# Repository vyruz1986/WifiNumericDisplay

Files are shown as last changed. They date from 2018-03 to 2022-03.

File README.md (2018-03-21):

# WiFi numeric display

## Introduction

This project is a generic 4-digit 7-segment numeric display which can be controlled over WiFi.
It uses a Wemos D1 Mini MCU and TPIC6B595 power logic shift registers to control pieces of powerful, very bright 24V LED strip segments.
These displays are highly visible even in bright sunlight over a long distance (used in Fyball competitions where viewing distance is around 30 meters).

It was created for use in Flyball, but can easily be applied elsewhere

Pictures & video: https://goo.gl/photos/G3tg8hrfvAJZ6PEY8

## Hardware

-Under construction-

Basically this is a 'beefed up' version of [Sparkfun's large 7 segment displays](https://www.sparkfun.com/products/8530)
together with [Sparkfun's accompanying large digit driver boards](https://www.sparkfun.com/products/13279).

The code is 1:1 compatible, the difference with my project is that I use the following components
to allow for better visibility (moar light!):

|Part type			| Sparkfun part						| My Part																	| Description																|
| --- | --- | --- | --- |
| Digit segment		| [12 SMD LEDs per segment (200mcd)](https://www.sparkfun.com/datasheets/Components/YSD-1600AR6F-89.pdf) driven with 12V	| 10cm of [24V 240 LED/meter strip](http://s.click.aliexpress.com/e/3zjiyZV)	| These are larger, more powerful LEDs which are also denser positioned.	|
| Segment driver	| [TPIC6C596](https://cdn.sparkfun.com/datasheets/Widgets/TPIC6C596.pdf) | [TPIC6B595](https://www.reichelt.de/?ACTION=3;ARTICLE=147328;SEARCH=tpic) | Compatible chip which can handle the extra current that out LED strip segments will draw |

I will complete this section later with a description on how to make the display using 10cm LED strip pieces and an aluminium plate to mount them on.

## Flashing the firmware

The firmware should flash just fine using the Arduino IDE with ESP8266 support. Open the `SevenSegmentDisplay.ino` file, select Wemos D1 mini as the board and hit flash.

You might want to change the OTA flash password in the `SevenSegmentDisplay.ino` file, search for the following line:
`#define OTA_PASSWD "EnterUniquePasswordHere!"`

## Connection & protocol

### Connecting to the display

The display listens on TCP port 23, no authentication is currently supported. Up to 5 clients can be connected simultaneously.

### Supported messages

Currently 2 messages are supported:

* `CDnnnn`: Where `nnnn` is a number between 0 and 9999. This message will start a countdown of the given number in seconds.
* `nnnn`: Where `nnnn` is a number between 0 and 9999. The number is expected to be an amount of time in hundredths of seconds. The time will be displayed in the format of SS.ss. e.g. sending `1234`, the display will show 12.34

Each message should be terminated by a newline (`\n`).

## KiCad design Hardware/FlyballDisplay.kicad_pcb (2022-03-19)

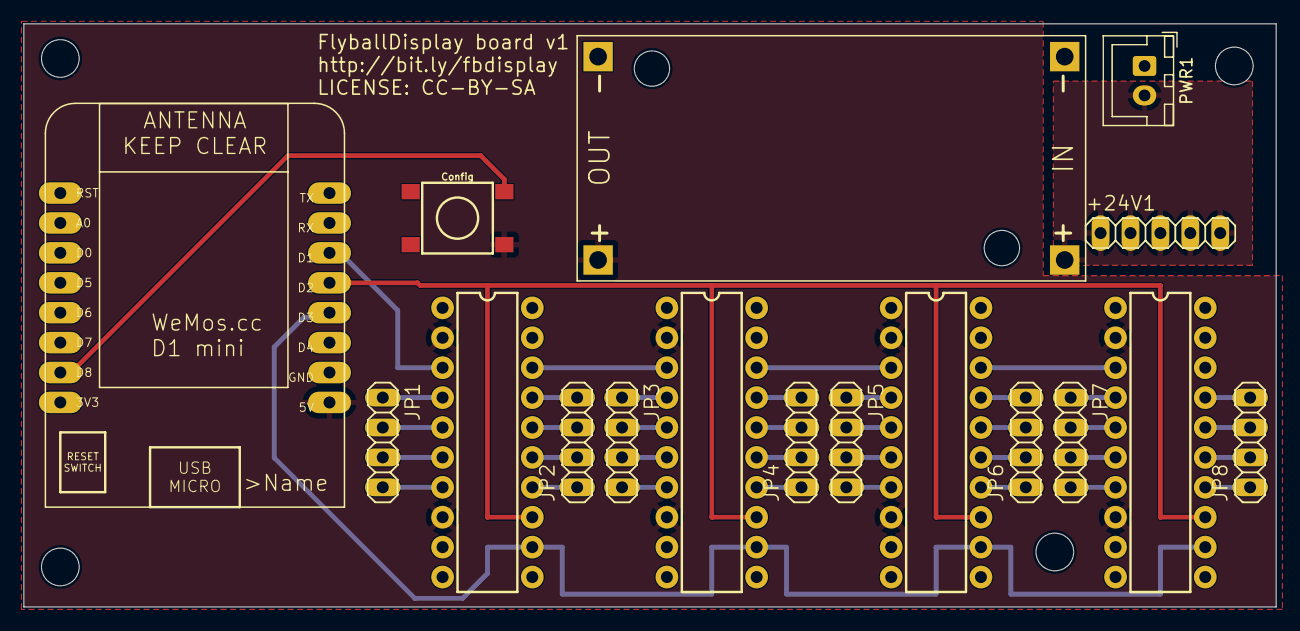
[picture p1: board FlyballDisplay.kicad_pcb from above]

Board: 2 copper layers, 106.3 x 49.5 mm, 18 parts (0 on the bottom side), 42 nets.

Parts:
+24V1: PINHD-1X5; 1X05
JP1, JP2, JP3, JP4, JP5, JP6, JP7, JP8: PINHD-1X4; 1X04
PWR1: 02-JST; JST_XH_B2B-XH-A_1x02_P2.50mm_Vertical
S1: MOMENTARY-SWITCH-SPST-SMD-6.2MM-TALL; TACTILE_SWITCH_SMD_6.2MM_TALL
U1, U2, U3, U4: TPIC6B595PTH; DIL20
U$1: DC-DC-STEP-DOWN-LM2596
U$2: A4L-LOC
WEMOS1: WEMOS-D1-MINI

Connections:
+5V: S1.A2 (1), U1.2 (VCC), U1.8 (~SRCLR), U2.2 (VCC), U2.8 (~SRCLR), U3.2 (VCC), U3.8 (~SRCLR), U4.2 (VCC), U4.8 (~SRCLR), U$1.OUT+, WEMOS1.5V
+24V: +24V1.1, +24V1.2, +24V1.3, +24V1.4, +24V1.5, PWR1.2, U$1.IN+
/CLOCK: U1.13 (SRCK), U2.13 (SRCK), U3.13 (SRCK), U4.13 (SRCK), WEMOS1.D2
/LATCH: U1.12 (RCK), U2.12 (RCK), U3.12 (RCK), U4.12 (RCK), WEMOS1.D3
GND: PWR1.1, U1.9 (~G), U1.10 (GND@10), U1.11 (GND@11), U1.19 (GND@19), U2.9 (~G), U2.10 (GND@10), U2.11 (GND@11), U2.19 (GND@19), U3.9 (~G), U3.10 (GND@10), U3.11 (GND@11), U3.19 (GND@19), U4.9 (~G), U4.10 (GND@10), U4.11 (GND@11), U4.19 (GND@19), U$1.IN-, U$1.OUT-, WEMOS1.GND
unnamed: JP1.1, U1.4 (D0)
unnamed: JP1.2, U1.5 (D1)
unnamed: JP1.3, U1.6 (D2)
unnamed: JP1.4, U1.7 (D3)
unnamed: JP2.1, U1.14 (D4)
unnamed: JP2.2, U1.15 (D5)
unnamed: JP2.3, U1.16 (D6)
unnamed: JP2.4, U1.17 (D7)
unnamed: JP3.1, U2.4 (D0)
unnamed: JP3.2, U2.5 (D1)
unnamed: JP3.3, U2.6 (D2)
unnamed: JP3.4, U2.7 (D3)
unnamed: JP4.1, U2.14 (D4)
unnamed: JP4.2, U2.15 (D5)
unnamed: JP4.3, U2.16 (D6)
unnamed: JP4.4, U2.17 (D7)
unnamed: JP5.1, U3.4 (D0)
unnamed: JP5.2, U3.5 (D1)
unnamed: JP5.3, U3.6 (D2)
unnamed: JP5.4, U3.7 (D3)
unnamed: JP6.1, U3.14 (D4)
unnamed: JP6.2, U3.15 (D5)
unnamed: JP6.3, U3.16 (D6)
unnamed: JP6.4, U3.17 (D7)
unnamed: JP7.1, U4.4 (D0)
unnamed: JP7.2, U4.5 (D1)
unnamed: JP7.3, U4.6 (D2)
unnamed: JP7.4, U4.7 (D3)
unnamed: JP8.1, U4.14 (D4)
unnamed: JP8.2, U4.15 (D5)
unnamed: JP8.3, U4.16 (D6)
unnamed: JP8.4, U4.17 (D7)
unnamed: S1.B2 (2), WEMOS1.D8
unnamed: U1.3 (SER_IN), WEMOS1.D1
unnamed: U1.18 (SER_OUT), U2.3 (SER_IN)
unnamed: U2.18 (SER_OUT), U3.3 (SER_IN)
unnamed: U3.18 (SER_OUT), U4.3 (SER_IN)

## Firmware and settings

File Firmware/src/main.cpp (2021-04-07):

/*
WifiNumericDisplay - A numeric 4-digit display which can be controlled over WiFi
Copyright (C) 2018  Alex Goris

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
You should have received a copy of the GNU General Public License
along with this program.  If not, see <http://www.gnu.org/licenses/>.
*/

#include <Arduino.h>
#include <FS.h> //this needs to be first, or it all crashes and burns...
#include <WiFiManager.h>
#include <DNSServer.h>
#include <ESP8266WebServer.h>
#include <NetworkServer.h>
#include <ESP8266WiFi.h>
#include <ESP8266mDNS.h>
#include <ArduinoOTA.h>
#include <math.h>
#include <ArduinoJson.h>

/**************************** Wifi Configuration ****************************/
String strHostname;
wl_status_t PrevWifiState;
WiFiManager wifiMan;

//static IP params
//default custom static IP
char static_ip[16] = "";
char static_gw[16] = "";
char static_sn[16] = "";

//flag for saving data
bool shouldSaveConfig = false;

/**************************** Secure Parameters - Do not publish!!!***********/
//OTA firmware upgrade password - Must match the one in board.txt file
#define OTA_PASSWD "EnterUniquePasswordHere!"

//GPIO declarations FOR 7 segment driver board
//-=-=-=-=-=-=-=-=-=-=-=-=-=-=-=-=-=-=-=-=-=-=-=-=
byte segmentClock = D2;
byte segmentLatch = D3;
byte segmentData = D1;
#define NUM_DIGITS 4

//Configure server which listens for incoming messages
WiFiServer ServerPort23(23);
NetworkServer MessageServer;

//Serial comms stuff
bool bInputStringComplete = false;
String strInputData;

//Countdown timer variables
int iCountDownTimer = 0;
int iCountDownCurrentValue = 0;
unsigned long ulCountDownStartTime = 0;

//Alive ping timer
#define ALIVE_PING_INTERVAL 5000
unsigned long ulLastAlivePing = 0;
unsigned long ulLastLEDOnTime = 0;
byte bLEDState = HIGH;
byte bPrevledState = HIGH;

//Reset NW button pin
#define RESET_NW_PIN D8
#define RESET_NW_PRESS_TIME 3000 //Time to press reset button before NW settings will be cleared
unsigned long ulButtonDepressTime = 0;

//Activity LED
#define ACTIVITY_LED_PIN LED_BUILTIN
unsigned long ulLEDLinkInterval = 1000; //every second
unsigned long ulLEDOnTime = 0;

void ResetNetwork();
void HandleNWResetButton();
void HandleActivityLED();
void HandleWifiConfig();
void StopCountDownTimer();
void StartCountDownTimer(unsigned int iSeconds);
void HandleCountDownTimer();
void serialEvent();
void postNumber(byte number, boolean decimal);
void ShowNumber(long lValue, uint8_t iNumDecimals);
void ClearDisplay();
void saveConfigCallback();

void setup()
{
   Serial.begin(74880);
   Serial.println();
   String realSize = String(ESP.getFlashChipRealSize());
   String ideSize = String(ESP.getFlashChipSize());
   bool flashCorrectlyConfigured = realSize.equals(ideSize);
   if (flashCorrectlyConfigured)
      SPIFFS.begin();
   else
      Serial.println("flash incorrectly configured, SPIFFS cannot start, IDE size: " + ideSize + ", real size: " + realSize);

   Serial.println("Starting setup...");
   //configure IO pins
   pinMode(RESET_NW_PIN, INPUT);
   pinMode(ACTIVITY_LED_PIN, OUTPUT);

   pinMode(segmentClock, OUTPUT);
   pinMode(segmentData, OUTPUT);
   pinMode(segmentLatch, OUTPUT);

   digitalWrite(segmentClock, LOW);
   digitalWrite(segmentData, LOW);
   digitalWrite(segmentLatch, LOW);

   //Clear display
   ClearDisplay();

   //Handle config
   Serial.printf("Starting wifi config\r\n");
   HandleWifiConfig();

   strHostname = WiFi.hostname();
   String strLocalIp = WiFi.localIP().toString();
   uint iLastIpPart = strLocalIp.substring(strLocalIp.lastIndexOf('.') + 1).toInt();
   ShowNumber(iLastIpPart, 0);
   Serial.printf("Connected to AP %s, IP: %s, name: %s\r\n", WiFi.SSID().c_str(), strLocalIp.c_str(), strHostname.c_str());

   ServerPort23.begin();
   MessageServer.init(&ServerPort23);

   //OTA Firmware update stuff
   // Port defaults to 8266
   ArduinoOTA.setPort(8266);

   // Hostname defaults to esp8266-[ChipID]
   //ArduinoOTA.setHostname("myesp8266");

   // No authentication by default
   ArduinoOTA.setPassword((const char *)OTA_PASSWD);

   ArduinoOTA.onStart([]() {
      Serial.printf("Receiving new OTA firmware...\r\n");
   });
   ArduinoOTA.onEnd([]() {
      Serial.printf("New firwmare received, rebooting!\r\n");
   });
   ArduinoOTA.onProgress([](unsigned int progress, unsigned int total) {
      Serial.printf("OTA Progress: %u%%\r", (progress / (total / 100)));
   });
   ArduinoOTA.onError([](ota_error_t error) {
      Serial.printf("OTA Error: %u", error);
   });
   ArduinoOTA.begin();

   Serial.printf("Starting!");
}

void loop()
{
   while (millis() < 3000)
   {
      //Don't do anything first 3 seconds so system can settle down a bit
      return;
   }

   //Call main loops
   serialEvent();
   MessageServer.Loop();
   HandleCountDownTimer();
   HandleActivityLED();
   HandleNWResetButton();
   ArduinoOTA.handle();
   if (MessageServer.Available())
   {
      strInputData = MessageServer.GetOldestData();
      bInputStringComplete = true;
   }

   //Check wifi status
   wl_status_t WifiState = WiFi.status();
   if (WifiState != PrevWifiState)
   {
      Serial.printf("Wifi state changed to: %s!\r\n", (WifiState != WL_CONNECTED ? "Connection lost" : "Connected"));
      if (WifiState == WL_CONNECTED)
      {
         //Show (potentially new) IP on display
         String strLocalIp = WiFi.localIP().toString();
         uint iLastIpPart = strLocalIp.substring(strLocalIp.lastIndexOf('.') + 1).toInt();
         ShowNumber(iLastIpPart, 0);
      }
      PrevWifiState = WifiState;
   }

   if (bInputStringComplete)
   {
      Serial.printf("Received data: %s\r\n", strInputData.c_str());

      if (strInputData.indexOf("CD") > -1)
      {
         //We should start a coundown timer
         unsigned int iRequestedCountDownTime = strInputData.substring(2).toInt();
         StartCountDownTimer(iRequestedCountDownTime);
         Serial.printf("Starting countdown for %i seconds...\r\n", iRequestedCountDownTime);
      }
      else if (strInputData == "CLR")
      {
         ClearDisplay();
         Serial.printf("Clearing display...\r\n");
      }
      else if (strInputData == "RSTNW")
      {
         //Reset network
         ResetNetwork();
      }
      else if (strInputData.toInt() >= -999 && strInputData.toInt() <= 9999)
      {
         StopCountDownTimer();
         ShowNumber(strInputData.toInt(), 2);
         Serial.printf("Showing number: %li ...\r\n", strInputData.toInt());
      }
      else
      {
         //Invalid data received, make logging
         Serial.printf("Invalid data received, don't know what to do with this: %s\r\n", strInputData.c_str());
      }

      //Reset input data for next loop
      bInputStringComplete = false;
      strInputData = "";
   }

   if (millis() - ulLastAlivePing > ALIVE_PING_INTERVAL)
   {
      Serial.printf("Alive for %li seconds!\r\n", millis() / 1000);
      ulLastAlivePing = millis();
   }

   yield(); //Allow background stuff to happen
}

//Clears display so all segments of all digits are OFF
void ClearDisplay()
{
   for (byte x = 0; x < NUM_DIGITS; x++)
   {
      postNumber(' ', false);
   }
   //Latch the current segment data
   digitalWrite(segmentLatch, LOW);
   digitalWrite(segmentLatch, HIGH);
   return;
}

//Displays a number.
void ShowNumber(long lValue, uint8_t iNumDecimals)
{
   byte x = 0;
   bool bNegative = false;
   int8_t iNumDigitsModifier = 0;

   Serial.printf("Got number %lu\r\n", lValue);

   if (lValue < 0)
   {
      //negative value, remember for later (first digit should be sent last)
      bNegative = true;
      iNumDigitsModifier = -1;
      lValue = abs(lValue);
   }
   while (x < (NUM_DIGITS + iNumDigitsModifier))
   {
      int remainder = lValue % 10;
      if (remainder == 0 && lValue == 0 && (x > iNumDecimals))
      {
         //Don't display prefix zeroes
         remainder = ' ';
      }
      Serial.printf("Calling PostNumber with data: %i (lVal: %li, x: %i)\r\n", remainder, lValue, x);
      postNumber(remainder, (x == iNumDecimals && iNumDecimals > 0));

      lValue /= 10;
      x++;
   }
   if (bNegative)
   {
      //Send negative symbol last (=first digit)
      postNumber('-', false);
   }

   //Latch the current segment data
   digitalWrite(segmentLatch, LOW);
   digitalWrite(segmentLatch, HIGH); //Register moves storage register on the rising edge of RCK
}

//Given a number, or '-', shifts it out to the display
void postNumber(byte number, boolean decimal)
{
   //    -  A
   //   / / F/B
   //    -  G
   //   / / E/C
   //    -. D/DP

#define a 1 << 0
#define b 1 << 6
#define c 1 << 5
#define d 1 << 4
#define e 1 << 3
#define f 1 << 1
#define g 1 << 2
#define dp 1 << 7

   byte segments = 0;

   switch (number)
   {
   case 1:
      segments = b | c;
      break;
   case 2:
      segments = a | b | d | e | g;
      break;
   case 3:
      segments = a | b | c | d | g;
      break;
   case 4:
      segments = f | g | b | c;
      break;
   case 5:
      segments = a | f | g | c | d;
      break;
   case 6:
      segments = a | f | g | e | c | d;
      break;
   case 7:
      segments = a | b | c;
      break;
   case 8:
      segments = a | b | c | d | e | f | g;
      break;
   case 9:
      segments = a | b | c | d | f | g;
      break;
   case 0:
      segments = a | b | c | d | e | f;
      break;
   case ' ':
      segments = 0;
      break;
   case 'c':
      segments = g | e | d;
      break;
   case '-':
      segments = g;
      break;
   }

   if (decimal)
      segments |= dp;

   Serial.printf("Writing data to SR: %i\r\n", segments);

   digitalWrite(segmentClock, LOW);
   shiftOut(segmentData, segmentClock, MSBFIRST, segments);
}

void serialEvent()
{
   //Listen on serial port
   Serial.flush();
   while (Serial.available() > 0)
   {
      char cInChar = Serial.read(); // Read a character
      if (cInChar == '\n')          //Check if buffer contains complete serial message, terminated by newline (\n)
      {
         //Serial message in buffer is complete, null terminate it and store it for further handling
         bInputStringComplete = true;
         //strInputData += '\0'; // Null terminate the string
         break;
      }
      strInputData += cInChar; // Store it
   }
}

void HandleCountDownTimer()
{
   if (iCountDownTimer == 0)
   {
      //No timer is set, do nothing
      return;
   }

   //How far are we?
   unsigned int iTimeExpired = (millis() - ulCountDownStartTime) / 1000;
   if ((int)(iCountDownTimer - iTimeExpired) != iCountDownCurrentValue)
   {
      ShowNumber(iCountDownTimer - iTimeExpired, 0);
      iCountDownCurrentValue = iCountDownTimer - iTimeExpired;
   }
   if (iCountDownCurrentValue == 0)
   {
      StopCountDownTimer();
   }
   return;
}

void StartCountDownTimer(unsigned int iSeconds)
{
   ulCountDownStartTime = millis();
   iCountDownTimer = iSeconds;
   iCountDownCurrentValue = iSeconds;
   //Make sure first number of countdown is shown
   ShowNumber(iCountDownTimer, 0);
   return;
}

void StopCountDownTimer()
{
   ulCountDownStartTime = 0;
   iCountDownTimer = 0;
   iCountDownCurrentValue = 0;
   return;
}

void HandleWifiConfig()
{
   //read configuration from FS json
   Serial.println("mounting FS...");

   if (SPIFFS.begin())
   {
      Serial.println("mounted file system");
      if (SPIFFS.exists("/config.json"))
      {
         //file exists, reading and loading
         Serial.println("reading config file");
         File configFile = SPIFFS.open("/config.json", "r");
         if (configFile)
         {
            Serial.println("opened config file");
            size_t size = configFile.size();
            // Allocate a buffer to store contents of the file.
            std::unique_ptr<char[]> buf(new char[size]);

            configFile.readBytes(buf.get(), size);
            DynamicJsonBuffer jsonBuffer;
            JsonObject &json = jsonBuffer.parseObject(buf.get());
            json.printTo(Serial);
            if (json.success())
            {
               Serial.println("\nparsed json");

               if (json["ip"])
               {
                  Serial.println("setting custom ip from config");
                  //static_ip = json["ip"];
                  strcpy(static_ip, json["ip"]);
                  strcpy(static_gw, json["gateway"]);
                  strcpy(static_sn, json["subnet"]);
                  //strcat(static_ip, json["ip"]);
                  //static_gw = json["gateway"];
                  //static_sn = json["subnet"];
                  Serial.println(static_ip);
                  /*            Serial.println("converting ip");
                  IPAddress ip = ipFromCharArray(static_ip);
                  Serial.println(ip);*/
               }
               else
               {
                  Serial.println("no custom ip in config");
               }
            }
            else
            {
               Serial.println("failed to load json config");
            }
         }
      }
   }
   else
   {
      Serial.println("failed to mount FS, formatting...");
      SPIFFS.format();
      ESP.reset();
   }

   //set config save notify callback
   wifiMan.setSaveConfigCallback(saveConfigCallback);

   //set static ip
   IPAddress _ip, _gw, _sn;
   _ip.fromString(static_ip);
   _gw.fromString(static_gw);
   _sn.fromString(static_sn);

   wifiMan.setSTAStaticIPConfig(_ip, _gw, _sn);

   //reset settings - for testing
   //wifiMan.resetSettings();

   //fetches ssid and pass and tries to connect
   //if it does not connect it starts an access point with the specified name
   //here  "AutoConnectAP"
   //and goes into a blocking loop awaiting configuration
   char ssid[20];
   snprintf(ssid, 20, "EJS-DSP-%08X", ESP.getChipId());
   Serial.printf("Starting access point with ssid %s\r\n", ssid);
   if (!wifiMan.autoConnect(ssid))
   {
      Serial.println("failed to connect and hit timeout");
      delay(3000);
      //reset and try again, or maybe put it to deep sleep
      ESP.reset();
   }

   //if you get here you have connected to the WiFi
   Serial.println("connected...yeey :)");

   //save the custom parameters to FS
   if (shouldSaveConfig)
   {
      Serial.println("saving config");
      DynamicJsonBuffer jsonBuffer;
      JsonObject &json = jsonBuffer.createObject();

      json["ip"] = WiFi.localIP().toString();
      json["gateway"] = WiFi.gatewayIP().toString();
      json["subnet"] = WiFi.subnetMask().toString();

      File configFile = SPIFFS.open("/config.json", "w");
      if (!configFile)
      {
         Serial.println("failed to open config file for writing");
      }

      json.prettyPrintTo(Serial);
      json.printTo(configFile);
      configFile.close();
      //end save
   }

   Serial.println("local ip");
   Serial.println(WiFi.localIP());
   Serial.println(WiFi.gatewayIP());
   Serial.println(WiFi.subnetMask());
}

void HandleActivityLED()
{
   if (millis() - ulLastLEDOnTime > (ulLEDLinkInterval + 100))
   {
      //LED should blink
      ulLastLEDOnTime = millis();
      ulLEDOnTime = millis();
   }

   if (millis() > ulLEDOnTime && millis() < (ulLEDOnTime + 100))
   {
      bPrevledState = bLEDState;
      bLEDState = LOW;
   }
   else
   {
      bPrevledState = bLEDState;
      bLEDState = HIGH;
   }

   if (bLEDState != bPrevledState)
   {
      digitalWrite(ACTIVITY_LED_PIN, bLEDState);
   }
}

void HandleNWResetButton()
{
   byte bButtonState = digitalRead(RESET_NW_PIN);
   if (bButtonState == HIGH)
   {
      //Button is being pressed, was this already the case?
      if (ulButtonDepressTime > 0 && millis() - ulButtonDepressTime > RESET_NW_PRESS_TIME)
      {
         //Button was pressed longer than required, trigger NW reset
         ResetNetwork();
      }
      else if (ulButtonDepressTime == 0)
      {
         //Button was pressed for the first time, set depress timestamp
         ulButtonDepressTime = millis();

         //Increase LED blink rate to acknowledge button press
         ulLEDLinkInterval = 200;
      }
   }
   else if (ulButtonDepressTime > 0)
   {
      //Button was pressed but not anymore, reset depress timestamp
      ulButtonDepressTime = 0;

      //Set LED blink rate back to normal operation
      ulLEDLinkInterval = 1000;
   }
}

void ResetNetwork()
{
   //We should clear wifi parameters
   Serial.printf("Received a request to clear network, I will restart with autoconfig AP after this!\r\n");
   digitalWrite(ACTIVITY_LED_PIN, LOW);
   wifiMan.resetSettings();
   ESP.eraseConfig();
   delay(3000);
   ESP.restart();
}

//callback notifying us of the need to save config
void saveConfigCallback()
{
   Serial.println("Should save config");
   shouldSaveConfig = true;
}

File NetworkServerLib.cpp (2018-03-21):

/*
WifiNumericDisplay - A numeric 4-digit display which can be controlled over WiFi
Copyright (C) 2018  Alex Goris

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
You should have received a copy of the GNU General Public License
along with this program.  If not, see <http://www.gnu.org/licenses/>.
*/

#include "NetworkServerLib.h"
#include <ESP8266WiFi.h>

void NetworkServer::init(WiFiServer* Server)
{
   _Server = Server;
   return;
}

void NetworkServer::Loop()
{
   _LogClientStates();
   _NetworkAccept();
   _NetworkListen();
}

String NetworkServer::GetOldestData()
{
   String strReturnString;
   
   if (!Available())
   {
      return strReturnString;
   }

   auto &OldestClient = _GetOldestClientWithDataComplete();

   if (OldestClient.bDataComplete)
   {
      strReturnString = OldestClient.strReceivedData;
      Serial.printf("Found data in client %i: '%s'!\r\n", 0, strReturnString.c_str());
      _ResetNetworkClient(OldestClient);
   }

   return strReturnString;
}

bool NetworkServer::Available()
{
   auto &OldestClient = _GetOldestClientWithDataComplete();
   if (OldestClient.bDataComplete)
   {
      return true;
   }
   return false;
}


void NetworkServer::_NetworkAccept()
{
   //Listen on server
   auto ClientObj = _Server->available();
   if (ClientObj.connected())
   {
      Serial.printf("Connection available\r\n");
      auto &Client = _GetFreeNetworkClient();
      Client.ClientObj = ClientObj;
      //client.flush();
      Serial.printf("Client connected!\r\n");
      Client.iLastActivityTime = millis();
      Client.bClientConnected = true;
   }
}
void NetworkServer::_NetworkListen()
{
   int i = 0;
   for (auto &Client : _NetworkClients)
   {
      //Handle client disconnects
      if (Client.bClientConnected
         && !Client.ClientObj.connected())
      {
         //Client has closed connection, close it from our side as well
         _ResetNetworkClient(Client);
         _DisconnectNetworkClient(Client);
      }

      //Serial.printf("Checking client %i: Connected %i(%i)\r\n", i, Client.bClientConnected, true);
      if (Client.bClientConnected
         && millis() - Client.iLastActivityTime > CLIENT_TIMEOUT
         && Client.strReceivedData.length() > 0)
      {
         //Timeout, reset buffer
         _ResetNetworkClient(Client);
         Serial.printf("No data received after timeout (%i\s), resetting buffer...\r\n", CLIENT_TIMEOUT / 1000);
      }
      else if (Client.ClientObj.available() > 0)
      {
         Serial.printf("Receiving: '");
         while (Client.ClientObj.available() > 0 && !Client.bDataComplete)
         {
            char cInChar = Client.ClientObj.read(); // Read a character
            //Check if this was an ENQ message
            if (cInChar == ENQ_MSG)
            {
               //ENQ received, confirm with ACK
               Client.ClientObj.write(ACK_MSG);
               return;
            }
            Serial.printf("%x", cInChar);
            if (cInChar == '\n') //Check if buffer contains complete message, terminated by newline (\n)
            {
               Serial.printf("'\r\n");
               //Message in buffer is complete, set complete marker
               Client.bDataComplete = true;
               Serial.printf("Received: '%s'\r\n", Client.strReceivedData.c_str());
               //And confirm with ACK to client
               Client.ClientObj.write(ACK_MSG);
               break;
            }
            Client.strReceivedData += cInChar; // Store it
         }
         Client.iLastActivityTime = millis();

      }
      i++;
   }
}

NetworkServer::_NetworkClient &NetworkServer::_GetFreeNetworkClient()
{
   _NetworkClient &OldestClient = _NetworkClients[0];
   bool bFreeClientFound = false;
   uint8_t i = 0;
   uint8_t iOldestClient = 0;
   for (auto &Client : _NetworkClients)
   {
      Serial.printf("Client %i last active: %lu\r\n", i, Client.iLastActivityTime);
      //Keep track of oldest client in case we have no more free ones
      if (Client.iLastActivityTime < OldestClient.iLastActivityTime)
      {
         OldestClient = Client;
         iOldestClient = i;
      }
      if (!Client.bClientConnected
         && Client.strReceivedData.length() == 0)
      {
         //Free client found, assign it
         Serial.printf("Found free client: %i\r\n", i);
         bFreeClientFound = true;
         return Client;
      }
      i++;
   }
   
   if (!bFreeClientFound)
   {
      //No free client is found.
      //Reset oldest (kick it out) and return that one
      Serial.printf("Using oldest client (%i) with alive time of %lu\r\n", iOldestClient, OldestClient.iLastActivityTime);
      _ResetNetworkClient(OldestClient);
      _DisconnectNetworkClient(OldestClient);
      return OldestClient;
   }
}

void NetworkServer::_ResetNetworkClient(_NetworkClient &Client)
{
   Serial.printf("Client buffer cleared\r\n");
   Client.bDataComplete = false;
   Client.strReceivedData = "";
}

void NetworkServer::_DisconnectNetworkClient(_NetworkClient &Client)
{
   if (Client.ClientObj.connected())
   {
      Client.ClientObj.stop();
   }
   Serial.printf("Client disconnected\r\n");
   Client.bClientConnected = false;
   Client.iLastActivityTime = 0;
   _ResetNetworkClient(Client);

}

NetworkServer::_NetworkClient& NetworkServer::_GetOldestClientWithDataComplete()
{
   _NetworkClient &OldestClient = _NetworkClients[0];
   int i = 0;
   for (auto &Client : _NetworkClients)
   {
      //Check each client if it is older and has valid data
      if (Client.iLastActivityTime < OldestClient.iLastActivityTime
         && Client.strReceivedData.length() > 0
         && Client.bDataComplete)
      {
         _NetworkClient& OldestClient = Client;
      }
      i++;
   }

   return OldestClient;
}

void NetworkServer::_LogClientStates()
{
   if (millis() - _ulLastStatusLog < 500)
   {
      return;
   }
   _ulLastStatusLog = millis();

   uint8_t i = 0;
   for (auto &Client : _NetworkClients)
   {
      Serial.printf("Client %i: C: %i | CO: %i | LaT: %lu\r\n", i, Client.bClientConnected, Client.ClientObj.connected(), Client.iLastActivityTime);
      i++;
   }
}

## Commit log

2021-04-07 feat: Added hardware folder with Kicad schematics and board files
    [FlyballDisplay-B_Mask.gbr, FlyballDisplay-B_SilkS.gbr, FlyballDisplay-Bottom.gbr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]
2022-03-19 fix: Replaced JST XH header with correct hole size and updated to KiCAD 6
    [FlyballDisplay-B_Mask.gbr, FlyballDisplay-B_Mask.gbs, FlyballDisplay-B_Paste.gbp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]

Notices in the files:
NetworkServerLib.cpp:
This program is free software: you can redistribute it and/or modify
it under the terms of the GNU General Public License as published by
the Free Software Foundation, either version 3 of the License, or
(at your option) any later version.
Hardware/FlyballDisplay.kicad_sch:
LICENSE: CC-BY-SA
